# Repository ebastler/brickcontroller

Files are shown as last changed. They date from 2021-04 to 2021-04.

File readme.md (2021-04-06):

# brickcontroller

This PCB was designed to be a replacement for the feature-lacking original controller of this construction-brick compatible light-kit: https://de.aliexpress.com/item/4001236916887.html

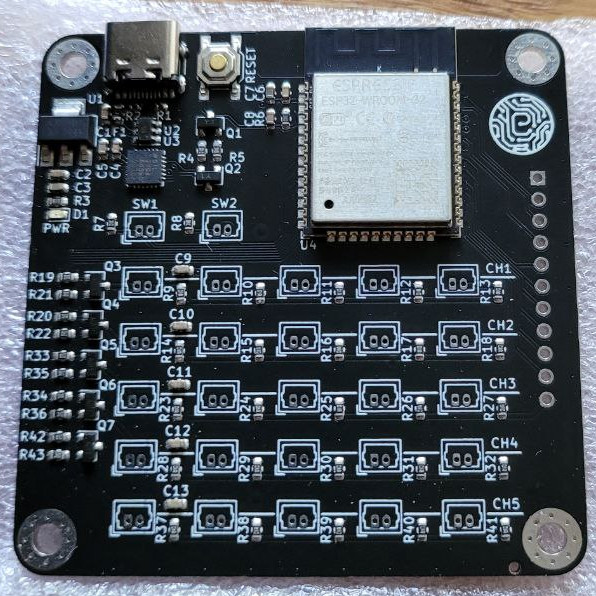
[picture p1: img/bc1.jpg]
front
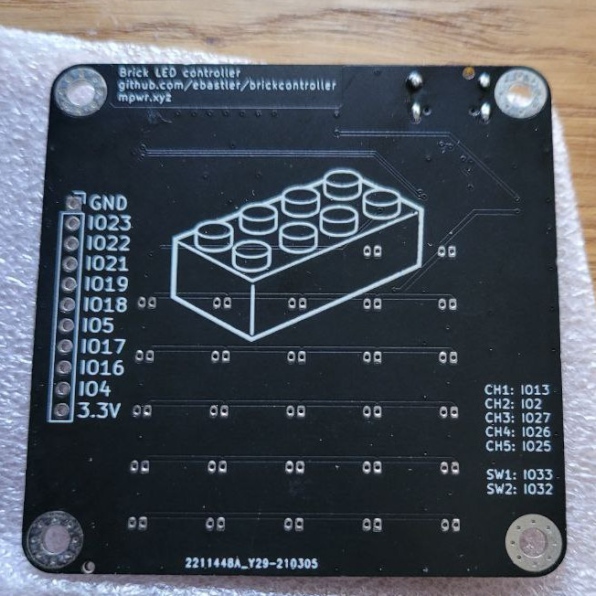
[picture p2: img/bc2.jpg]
back
|  |  |
| --- | --- |

My PCB supports 5 channels with 5 connectors each, but splitters for those lights exist, so more than 25 LEDs can be connected at a time. 100 Ohm series resistors for each LED connector protect the board from accidental short circuits on all outputs. The maximum current is defined by both the 500 mA input fuse, as well as the USB 2.0 Type C connector, which does not perform any current negotiation higher than the USB2.0 base specs, but that should be hard to reach with a somewhat reasonable amount of LEDs.

The PCB uses an ESP32 module, which can be programmed over the same USB port that is also used for power. The necessary CP2104 UART bridge is included, as well as basic components to allow easy flashing of the ESP, similar to espressif devboards and adafruit feather boards. Two additional connectors can be used for external buttons (active high), allowing direct control of the LEDs, while 9 GPIOs are broken out into an optional (2.54 mm) header for possible expansions.

Gerber files, as well as jlcpbc compatible BOM and CPL files are included. Everything apart from the connectors (Molex Picoblade 2pin, sometimes referred to as ["micro JST"](https://de.aliexpress.com/item/32762054144.html) on Aliexpress) can be soldered by jlcpcb. The connectors are through-hole and easy to hand-solder.

Since this design was done for a friend of mine, I will not provide any software myself. You can either wait for his (WIFI+MQTT capable) software, or program something on your own. The hardware is tested and confirmed working.

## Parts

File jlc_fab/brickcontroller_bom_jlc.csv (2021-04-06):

Comment | Designator | Footprint | LCSC Part #
1u | C1,C2,C8 | C_0603_1608Metric | C15849
4.7u | C5,C9,C10,C11,C12,C13 | C_0603_1608Metric | C19666
100n | C6,C4 | C_0603_1608Metric | C14663
10u | C7,C3 | C_0603_1608Metric | C19702
PWR | D1 | LED_0603_1608Metric | C72038
750 mA | F1 | Fuse_0603_1608Metric | C20792
USB_C_Receptacle_USB2.0 | J1 | USB_C_Receptacle_HRO_TYPE-C-31-M-12 | C165948
SS8050 | Q1,Q2 | SOT-23 | C2150
AO3400A | Q3,Q4,Q5,Q6,Q7 | SOT-23 | C347475
5.1k | R1,R2 | R_0402_1005Metric | C25905
1k | R3 | R_0603_1608Metric | C21190
10k | R5,R4,R6,R7,R8,R21,R22,R36,R35,R43 | R_0603_1608Metric | C25804
100R | R10,R11,R12,R13,R19,R14,R15,R16,R17,R18,R20,R23,R24,R25,R26,R27,R33,R28,R29,R30,R31,R32,R34,R37,R38,R39,R40,R41,R42,R9 | R_0603_1608Metric | C22775
SW_Push | SW1 | SW_SPST_SKQG_WithoutStem | C318884
AMS1117-3.3 | U1 | SOT-223-3_TabPin2 | C6186
SRV05-4 | U2 | SOT-23-6 | C85364
CP2104 | U3 | QFN-24-1EP_4x4mm_P0.5mm_EP2.6x2.6mm | C47742
ESP32-WROOM-32 | U4 | ESP32-WROOM-32 | C82899

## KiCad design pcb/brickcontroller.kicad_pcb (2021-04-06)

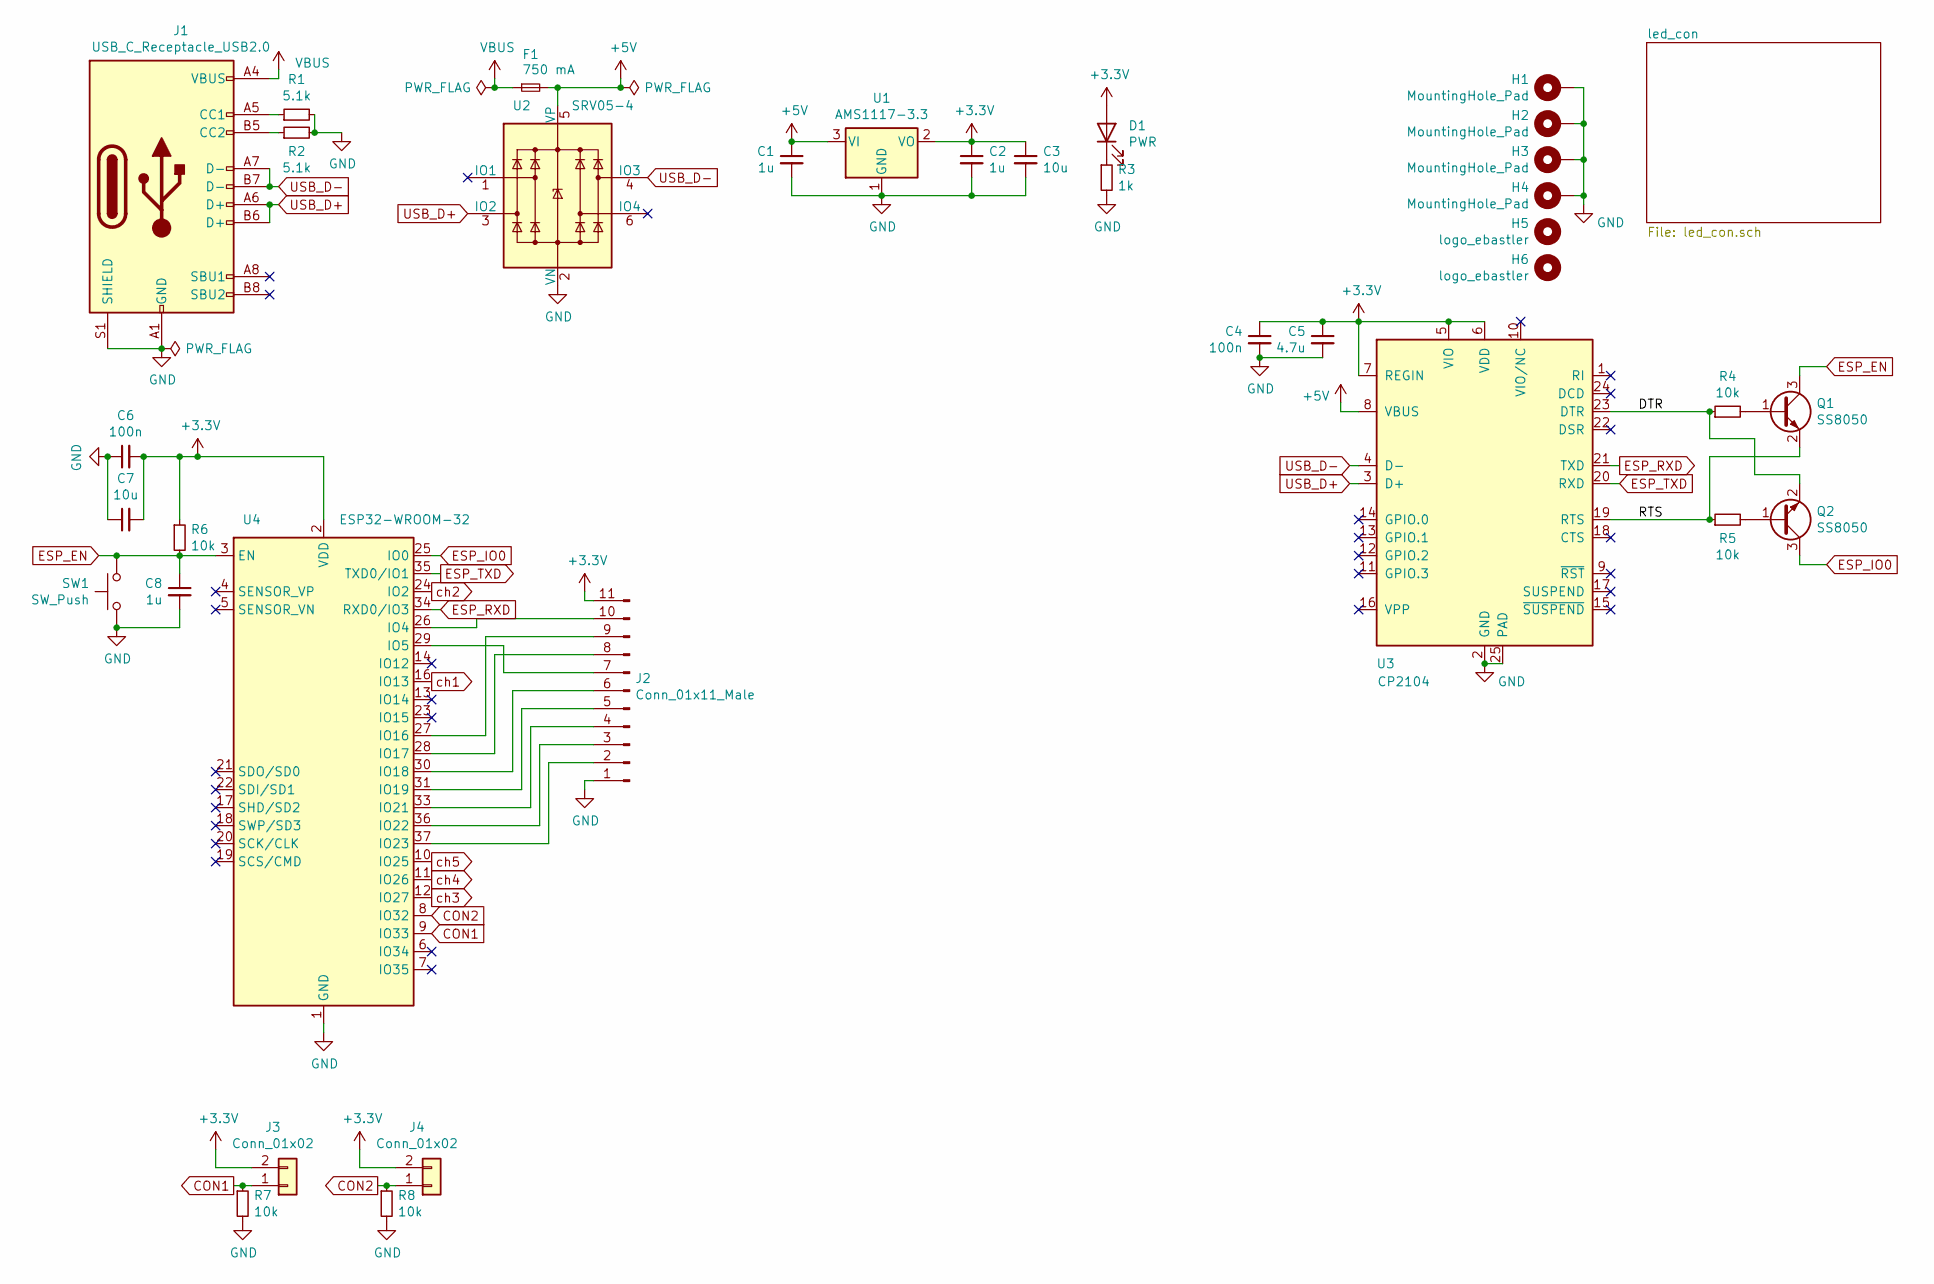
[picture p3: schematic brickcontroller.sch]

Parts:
C1, C2, C8: 1u; C_0603_1608Metric; LCSC C15849
C3, C7: 10u; C_0603_1608Metric; LCSC C19702
C4, C6: 100n; C_0603_1608Metric; LCSC C14663
C5: 4.7u; C_0603_1608Metric; LCSC C19666
D1: PWR; LED_0603_1608Metric; LCSC C72038
F1: 750 mA; Fuse_0603_1608Metric; LCSC C20792
H1, H2, H3, H4: MountingHole_Pad; MountingHole_3.2mm_M3_Pad_Via
H5: logo_ebastler; logo_silk_7p5
H6: logo_ebastler; brick
J1: USB_C_Receptacle_USB2.0; USB_C_Receptacle_HRO_TYPE-C-31-M-12; LCSC C165948
J2: Conn_01x11_Male; PinSocket_1x11_P2.54mm_Vertical
J3, J4: Conn_01x02; Molex_PicoBlade_53047-0210_1x02_P1.25mm_Vertical
Q1, Q2: SS8050; SOT-23; LCSC C2150
R1, R2: 5.1k; R_0402_1005Metric; LCSC C25905
R3: 1k; R_0603_1608Metric; LCSC C21190
R4, R5, R6, R7, R8: 10k; R_0603_1608Metric; LCSC C25804
SW1: SW_Push; SW_SPST_SKQG_WithoutStem; LCSC C318884
U1: AMS1117-3.3; SOT-223-3_TabPin2; LCSC C6186
U2: SRV05-4; SOT-23-6; LCSC C85364
U3: CP2104; QFN-24-1EP_4x4mm_P0.5mm_EP2.6x2.6mm; LCSC C47742
U4: ESP32-WROOM-32; LCSC C82899

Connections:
+3V3: C2.1, C3.1, C4.1, C5.1, C6.2, C7.2, D1.2 (A), J2.11, J3.2, J4.2, R6.1, U1.2 (VO), U3.5 (VIO), U3.6 (VDD), U3.7 (REGIN), U4.2 (VDD); also elsewhere on the board
+5V: C1.1, F1.2, U1.3 (VI), U2.5 (VP), U3.8 (VBUS)
/DTR: Q2.2 (E), R4.1, U3.23 (DTR)
/RTS: Q1.2 (E), R5.1, U3.19 (RTS)
CON1: J3.1, R7.1, U4.9 (IO33)
CON2: J4.1, R8.1, U4.8 (IO32)
ESP_EN: C8.1, Q1.3 (C), R6.2, SW1.2, U4.3 (EN)
ESP_IO0: Q2.3 (C), U4.25 (IO0)
ESP_RXD: U3.21 (TXD), U4.34 (RXD0/IO3)
ESP_TXD: U3.20 (RXD), U4.35 (TXD0/IO1)
GND: C1.2, C2.2, C3.2, C4.2, C5.2, C6.1, C7.1, C8.2, H1.1, H2.1, H3.1, H4.1, J1.A1 (GND), J1.A12 (GND), J1.B1 (GND), J1.B12 (GND), J1.S1 (SHIELD), J2.1, R1.2, R2.2, R3.2, R7.2, R8.2, SW1.1, U1.1 (GND), U2.2 (VN), U3.2 (GND), U3.25 (PAD), U4.1 (GND), U4.15 (GND), U4.38 (GND), U4.39 (GND); also elsewhere on the board
unnamed: D1.1 (K), R3.1
unnamed: J1.A5 (CC1), R1.1
unnamed: J1.B5 (CC2), R2.1
unnamed: J2.2, U4.37 (IO23)
unnamed: J2.3, U4.36 (IO22)
unnamed: J2.4, U4.33 (IO21)
unnamed: J2.5, U4.31 (IO19)
unnamed: J2.6, U4.30 (IO18)
unnamed: J2.7, U4.29 (IO5)
unnamed: J2.8, U4.28 (IO17)
unnamed: J2.9, U4.27 (IO16)
unnamed: J2.10, U4.26 (IO4)
unnamed: Q1.1 (B), R4.2
unnamed: Q2.1 (B), R5.2
USB_D+: J1.A6 (D+), J1.B6 (D+), U2.3 (IO2), U3.3 (D+)
USB_D-: J1.A7 (D-), J1.B7 (D-), U2.4 (IO3), U3.4 (D-)
VBUS: F1.1, J1.A4 (VBUS), J1.A9 (VBUS), J1.B4 (VBUS), J1.B9 (VBUS)
ch1: U4.16 (IO13); also elsewhere on the board
ch2: U4.24 (IO2); also elsewhere on the board
ch3: U4.12 (IO27); also elsewhere on the board
ch4: U4.11 (IO26); also elsewhere on the board
ch5: U4.10 (IO25); also elsewhere on the board

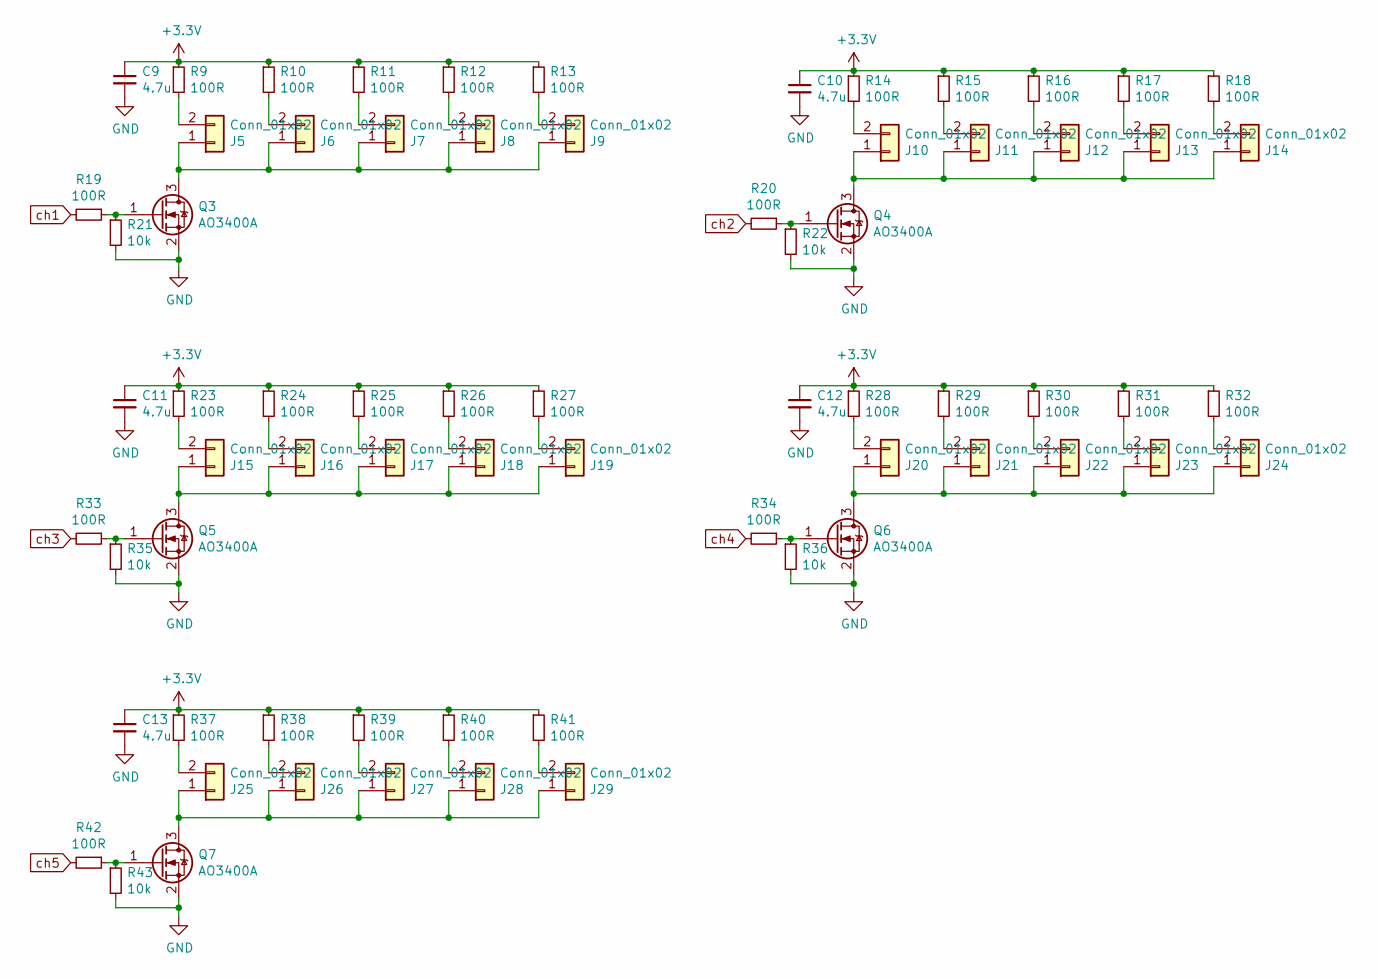
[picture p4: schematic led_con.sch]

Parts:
C9, C10, C11, C12, C13: 4.7u; C_0603_1608Metric; LCSC C19666
J5, J6, J7, J8, J9, J10, J11, J12, J13, J14, J15, J16, J17, J18, J19, J20, J21, J22, J23, J24, J25, J26, J27, J28, J29: Conn_01x02; Molex_PicoBlade_53047-0210_1x02_P1.25mm_Vertical
Q3, Q4, Q5, Q6, Q7: AO3400A; SOT-23; LCSC C347475
R9, R10, R11, R12, R13, R14, R15, R16, R17, R18, R19, R20, R23, R24, R25, R26, R27, R28, R29, R30, R31, R32, R33, R34, R37, R38, R39, R40, R41, R42: 100R; R_0603_1608Metric; LCSC C22775
R21, R22, R35, R36, R43: 10k; R_0603_1608Metric; LCSC C25804

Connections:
+3V3: C9.1, C10.1, C11.1, C12.1, C13.1, R9.1, R10.1, R11.1, R12.1, R13.1, R14.1, R15.1, R16.1, R17.1, R18.1, R23.1, R24.1, R25.1, R26.1, R27.1, R28.1, R29.1, R30.1, R31.1, R32.1, R37.1, R38.1, R39.1, R40.1, R41.1; also elsewhere on the board
GND: C9.2, C10.2, C11.2, C12.2, C13.2, Q3.2 (S), Q4.2 (S), Q5.2 (S), Q6.2 (S), Q7.2 (S), R21.2, R22.2, R35.2, R36.2, R43.2; also elsewhere on the board
unnamed: J5.1, J6.1, J7.1, J8.1, J9.1, Q3.3 (D)
unnamed: J5.2, R9.2
unnamed: J6.2, R10.2
unnamed: J7.2, R11.2
unnamed: J8.2, R12.2
unnamed: J9.2, R13.2
unnamed: J10.1, J11.1, J12.1, J13.1, J14.1, Q4.3 (D)
unnamed: J10.2, R14.2
unnamed: J11.2, R15.2
unnamed: J12.2, R16.2
unnamed: J13.2, R17.2
unnamed: J14.2, R18.2
unnamed: J15.1, J16.1, J17.1, J18.1, J19.1, Q5.3 (D)
unnamed: J15.2, R23.2
unnamed: J16.2, R24.2
unnamed: J17.2, R25.2
unnamed: J18.2, R26.2
unnamed: J19.2, R27.2
unnamed: J20.1, J21.1, J22.1, J23.1, J24.1, Q6.3 (D)
unnamed: J20.2, R28.2
unnamed: J21.2, R29.2
unnamed: J22.2, R30.2
unnamed: J23.2, R31.2
unnamed: J24.2, R32.2
unnamed: J25.1, J26.1, J27.1, J28.1, J29.1, Q7.3 (D)
unnamed: J25.2, R37.2
unnamed: J26.2, R38.2
unnamed: J27.2, R39.2
unnamed: J28.2, R40.2
unnamed: J29.2, R41.2
unnamed: Q3.1 (G), R19.1, R21.1
unnamed: Q4.1 (G), R20.1, R22.1
unnamed: Q5.1 (G), R33.1, R35.1
unnamed: Q6.1 (G), R34.1, R36.1
unnamed: Q7.1 (G), R42.1, R43.1
ch1: R19.2; also elsewhere on the board
ch2: R20.2; also elsewhere on the board
ch3: R33.2; also elsewhere on the board
ch4: R34.2; also elsewhere on the board
ch5: R42.2; also elsewhere on the board

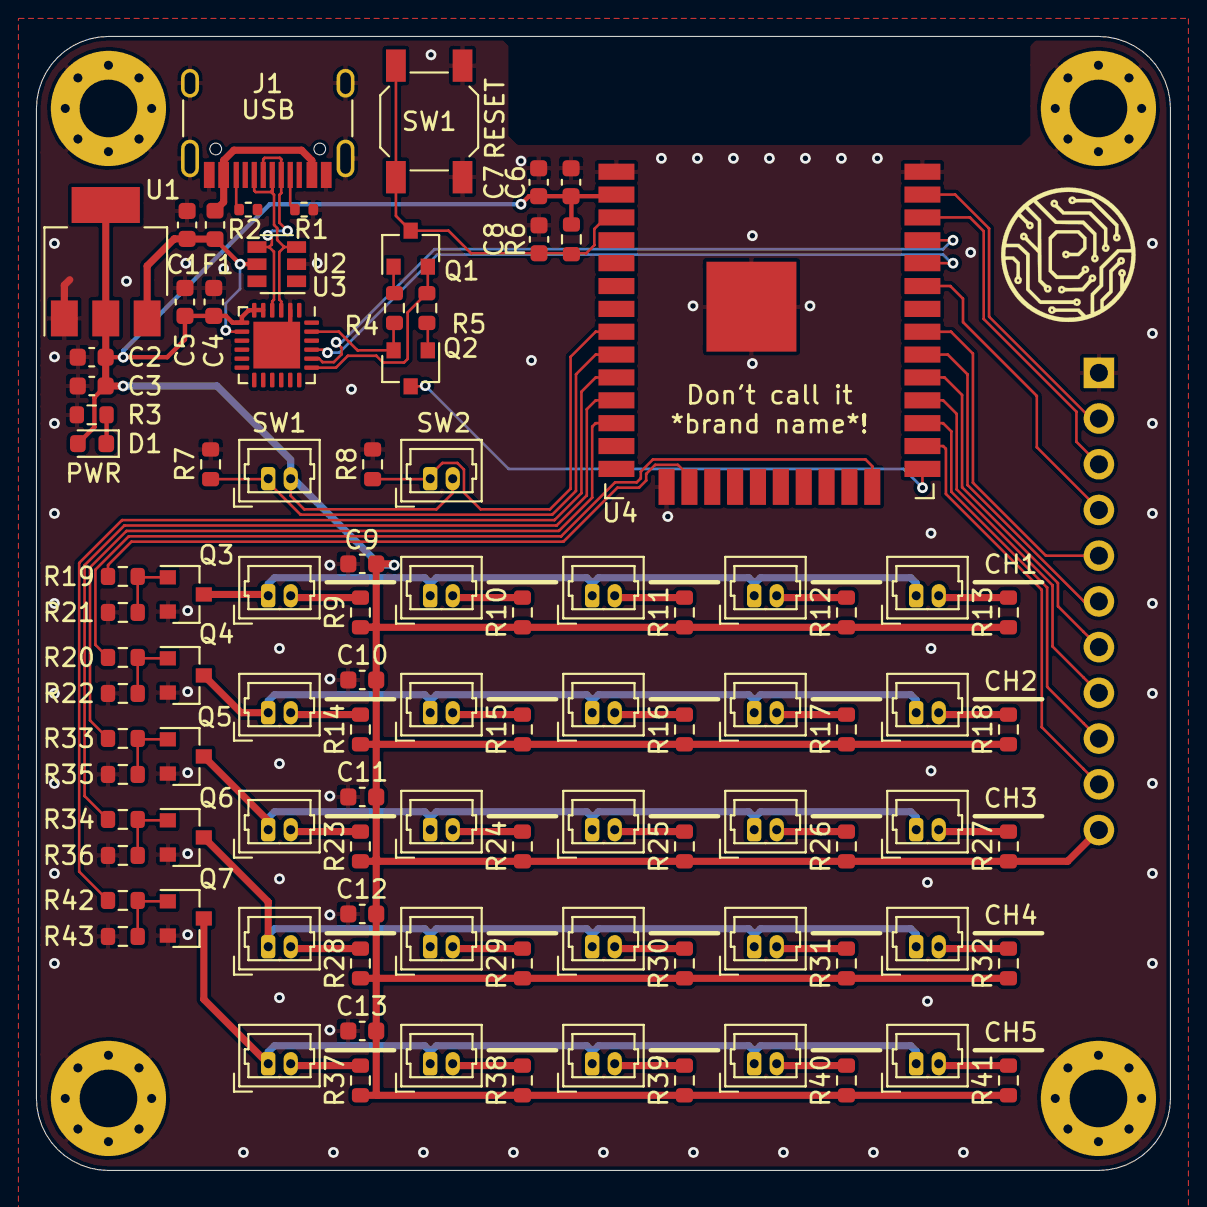
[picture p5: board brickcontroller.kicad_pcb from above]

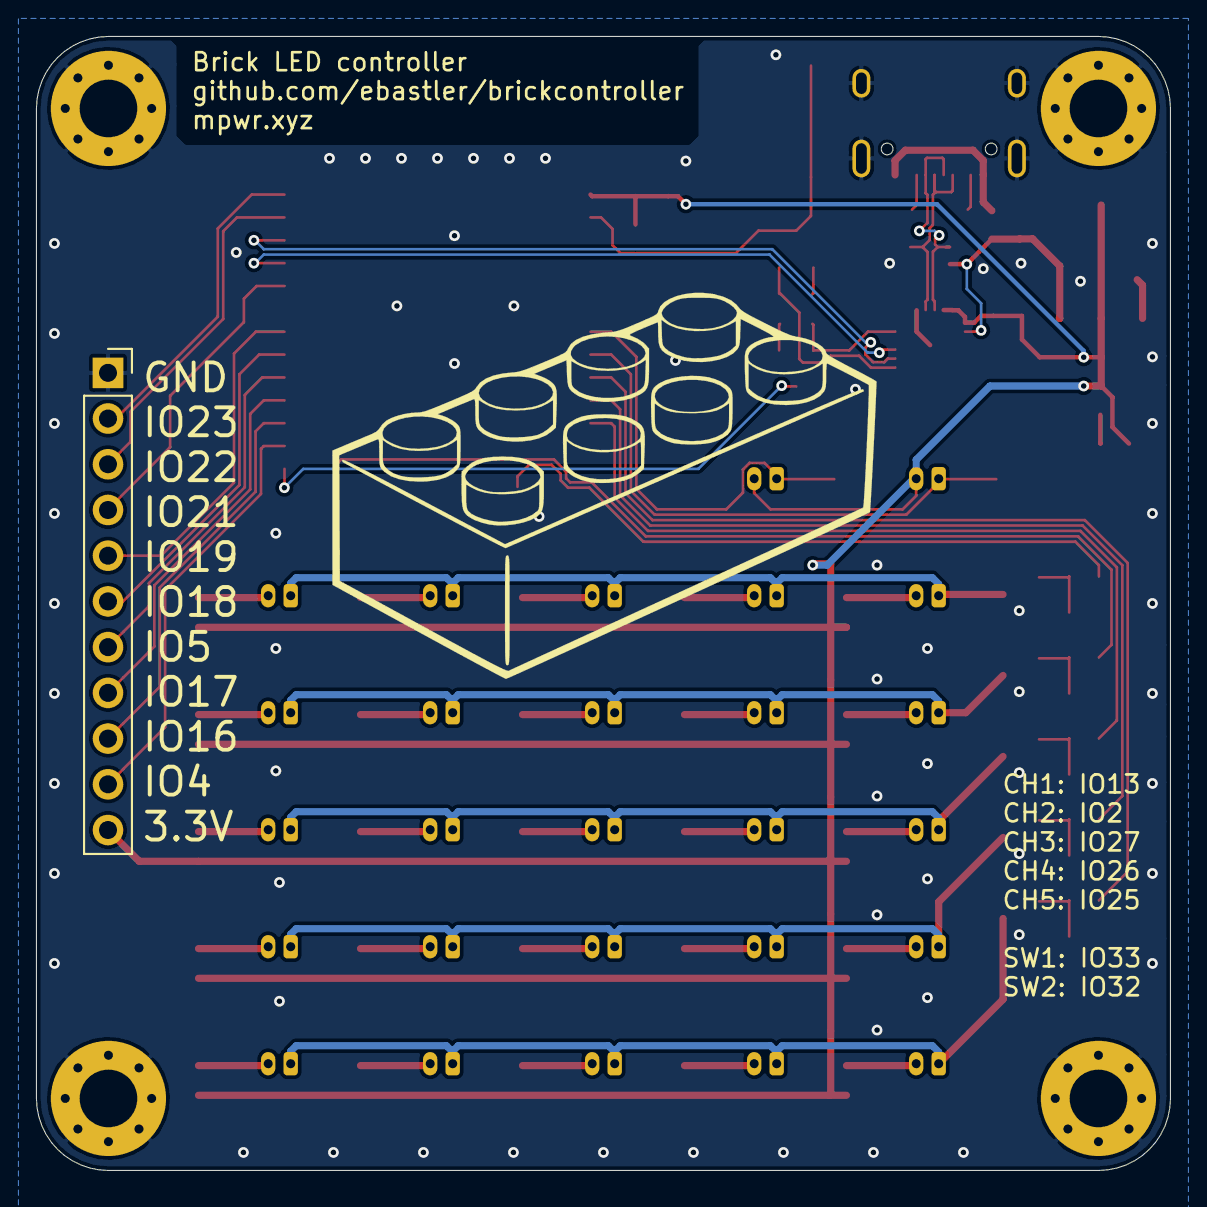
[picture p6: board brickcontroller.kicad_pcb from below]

Board: 2 copper layers, 63.0 x 63.0 mm, 105 parts (2 on the bottom side), 68 nets.

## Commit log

2021-04-06 improved schematic readability
    [brickcontroller.sch]
2021-04-06 added bom + cpl
    [brickcontroller_bom_jlc.csv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]
